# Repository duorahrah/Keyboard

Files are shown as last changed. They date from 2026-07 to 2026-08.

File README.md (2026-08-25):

# Custom 75% Mechanical Keyboard
Designed and built fully custom mechanical keyboard end-to-end, PCB design (KiCad), case design (Onshape) and 3D printing, and firmware (QMK on RP2040).\


## PCB Design



<br/>
-	Designed a RP2040-based custom mechanical keyboard PCB in KiCad with full keyboard matrix and USB-C connectivity
-	Includes full RP2040 support circuitry (crystal, QSPI flash, decoupling, reset and BOOTSEL)
-	Routed and manufactured the PCB

## Case Design

<br/>
-	Modeled custom case in Onshape, accounting for PCB mounting points, USB-C cutout, and switch plate clearance 

## Firmware
-	Developed custom QMK firmware for the keyboard, including multi-layer keymap and matrix/layout configuration to match the custom PCB design

## Challenges
-	USB and RP2040 debugging – I encountered an issue where the keyboard could not be detected by my computer while trying to flash the firmware. I was able to identify the issue as a short between the D+/D- connections through systematic multimeter-based debugging and fix it.
-	3D printer calibration - Case was printed using secondhand ELEGOO Neptune 4 Max, a printer which is known to be finnicky. I did research and looked at experiences from others who had the same printer to learn how to properly calibrate the printer, including replacing the bed springs with silicon spacers, and altering the printer’s configuration file to automatically level the bed and generate a printing mesh. 
-	Obtaining tools and materials – I was unable to gain access to public/free 3D printers over the summer, so I purchased a secondhand printer off Facebook Marketplace. The PCB and parts were ordered from JLCPCB and DigiKey (including $40 for international shipping D:). 

## Results
-	Successfully designed, manufactured, and assembled a working mechanical keyboard for daily use
-	Gained experience across PCB design, mechanical design, manufacturing, firmware development, and hardware debugging

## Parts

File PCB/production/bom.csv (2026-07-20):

Designator | Footprint | Quantity | Value | LCSC Part #
BOOT1, RST1 | SW_SPST_TL3342 | 2 | SW_Push
C1, C10, C2, C3, C6 | 0402 | 5 | 1u
C11, C12 | 0402 | 2 | 22p
C13, C14, C15, C16, C4, C7, C8, C9 | 0402 | 8 | 100n
C5 | 0603 | 1 | 10u
D1, D10, D11, D12, D13, D14, D15, D16, D17, D18, D19, D2, D20, D21, D22, D23, D24, D25, D26, D27, D28, D29, D3, D30, D31, D32, D33, D34, D35, D36, D37, D38, D39, D4, D40, D41, D42, D43, D44, D45, D46, D47, D48, D49, D5, D50, D51, D52, D53, D54, D55, D56, D57, D58, D59, D6, D60, D61, D62, D63, D64, D65, D66, D67, D68, D69, D7, D70, D71, D72, D73, D74, D75, D76, D77, D78, D79, D8, D80, D81, D82, D83, D84, D85, D86, D9 | D_SOD-123 | 86 | D_Small
F1 | 1206 | 1 | Fuse_Small
J1 | JST_SH_SM04B-SRSS-TB_1x04-1MP_P1.00mm_Horizontal | 1 | Conn_01x04
J2 | USB_C_Receptacle_HRO_TYPE-C-31-M-12 | 1 | USB_C_Receptacle_USB2.0_16P
J3 | PinHeader_1x05_P2.54mm_Vertical | 1 | Conn_01x05
MX1, MX10, MX11, MX12, MX13, MX14, MX15, MX16, MX17, MX18, MX19, MX2, MX20, MX21, MX22, MX23, MX24, MX25, MX26, MX27, MX28, MX29, MX3, MX30, MX31, MX33, MX34, MX35, MX36, MX37, MX38, MX39, MX4, MX40, MX41, MX42, MX43, MX44, MX46, MX47, MX49, MX5, MX50, MX51, MX52, MX53, MX54, MX55, MX56, MX57, MX58, MX59, MX6, MX60, MX61, MX62, MX63, MX64, MX65, MX66, MX67, MX68, MX69, MX7, MX70, MX71, MX72, MX73, MX75, MX76, MX8, MX80, MX81, MX82, MX83, MX84, MX85, MX86, MX9 | SW_MX_HS_CPG151101S11_1u | 79 | MX_SW_HS
MX32, MX45 | SW_MX_HS_CPG151101S11_1.5u | 2 | MX_SW_HS
MX48, MX74 | SW_MX_HS_CPG151101S11_1.75u | 2 | MX_SW_HS
MX77, MX78, MX79 | SW_MX_HS_KS-2P02B01-01_1.25u | 3 | MX_SW_HS
R1, R2 | 0402 | 2 | 5.1k
R3, R4, R5 | 0402 | 3 | 5k1
R6, R9 | 0402 | 2 | 1k
R7, R8 | 0402 | 2 | 27
S1 | STAB_MX_P_2u | 1 | MX_stab
S2, S3 | STAB_MX_P_2.25u | 2 | MX_stab
S4 | STAB_MX_P_6.25u | 1 | MX_stab
U1 | SOT-23-3 | 1 | XC6206PxxxMR
U2 | SOT-23-6 | 1 | SRV05-4
U3 | QFN-56-1EP_7x7mm_P0.4mm_EP3.2x3.2mm | 1 | RP2040
U4 | SOIC-8_5.3x5.3mm_P1.27mm | 1 | W25Q128JVS
Y1 | Crystal_SMD_3225-4Pin_3.2x2.5mm | 1 | Crystal_GND24

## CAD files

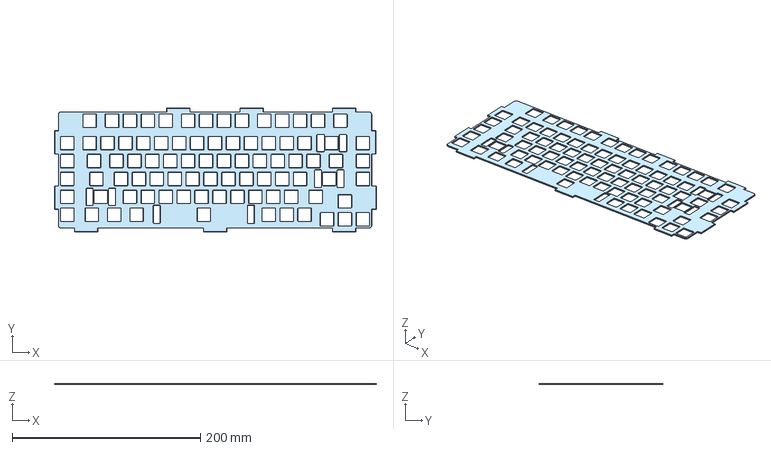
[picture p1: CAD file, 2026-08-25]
Case/plate (3).step
342.4 x 131.8 x 1.50 mm

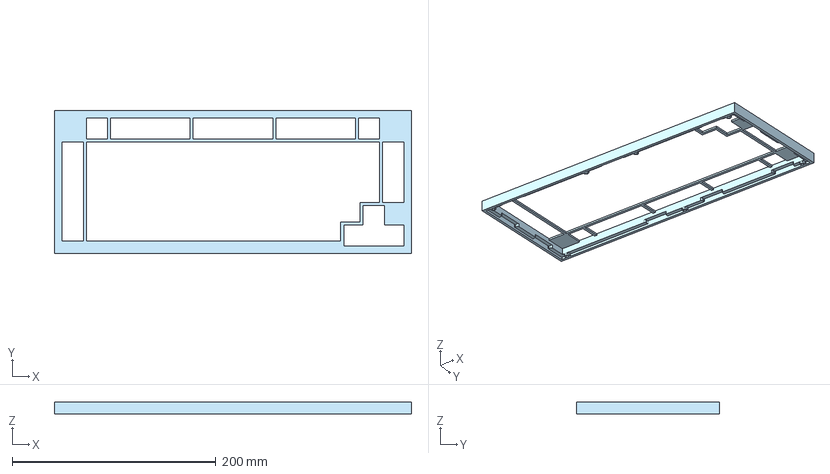
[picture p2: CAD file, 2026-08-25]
Case/Top Case.step
350.2 x 140.6 x 12.0 mm

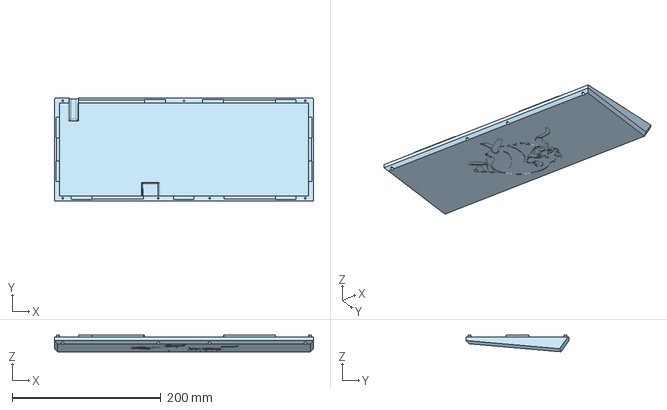
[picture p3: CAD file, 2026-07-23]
Case/Bottom Case.step
348.2 x 138.6 x 22.5 mm

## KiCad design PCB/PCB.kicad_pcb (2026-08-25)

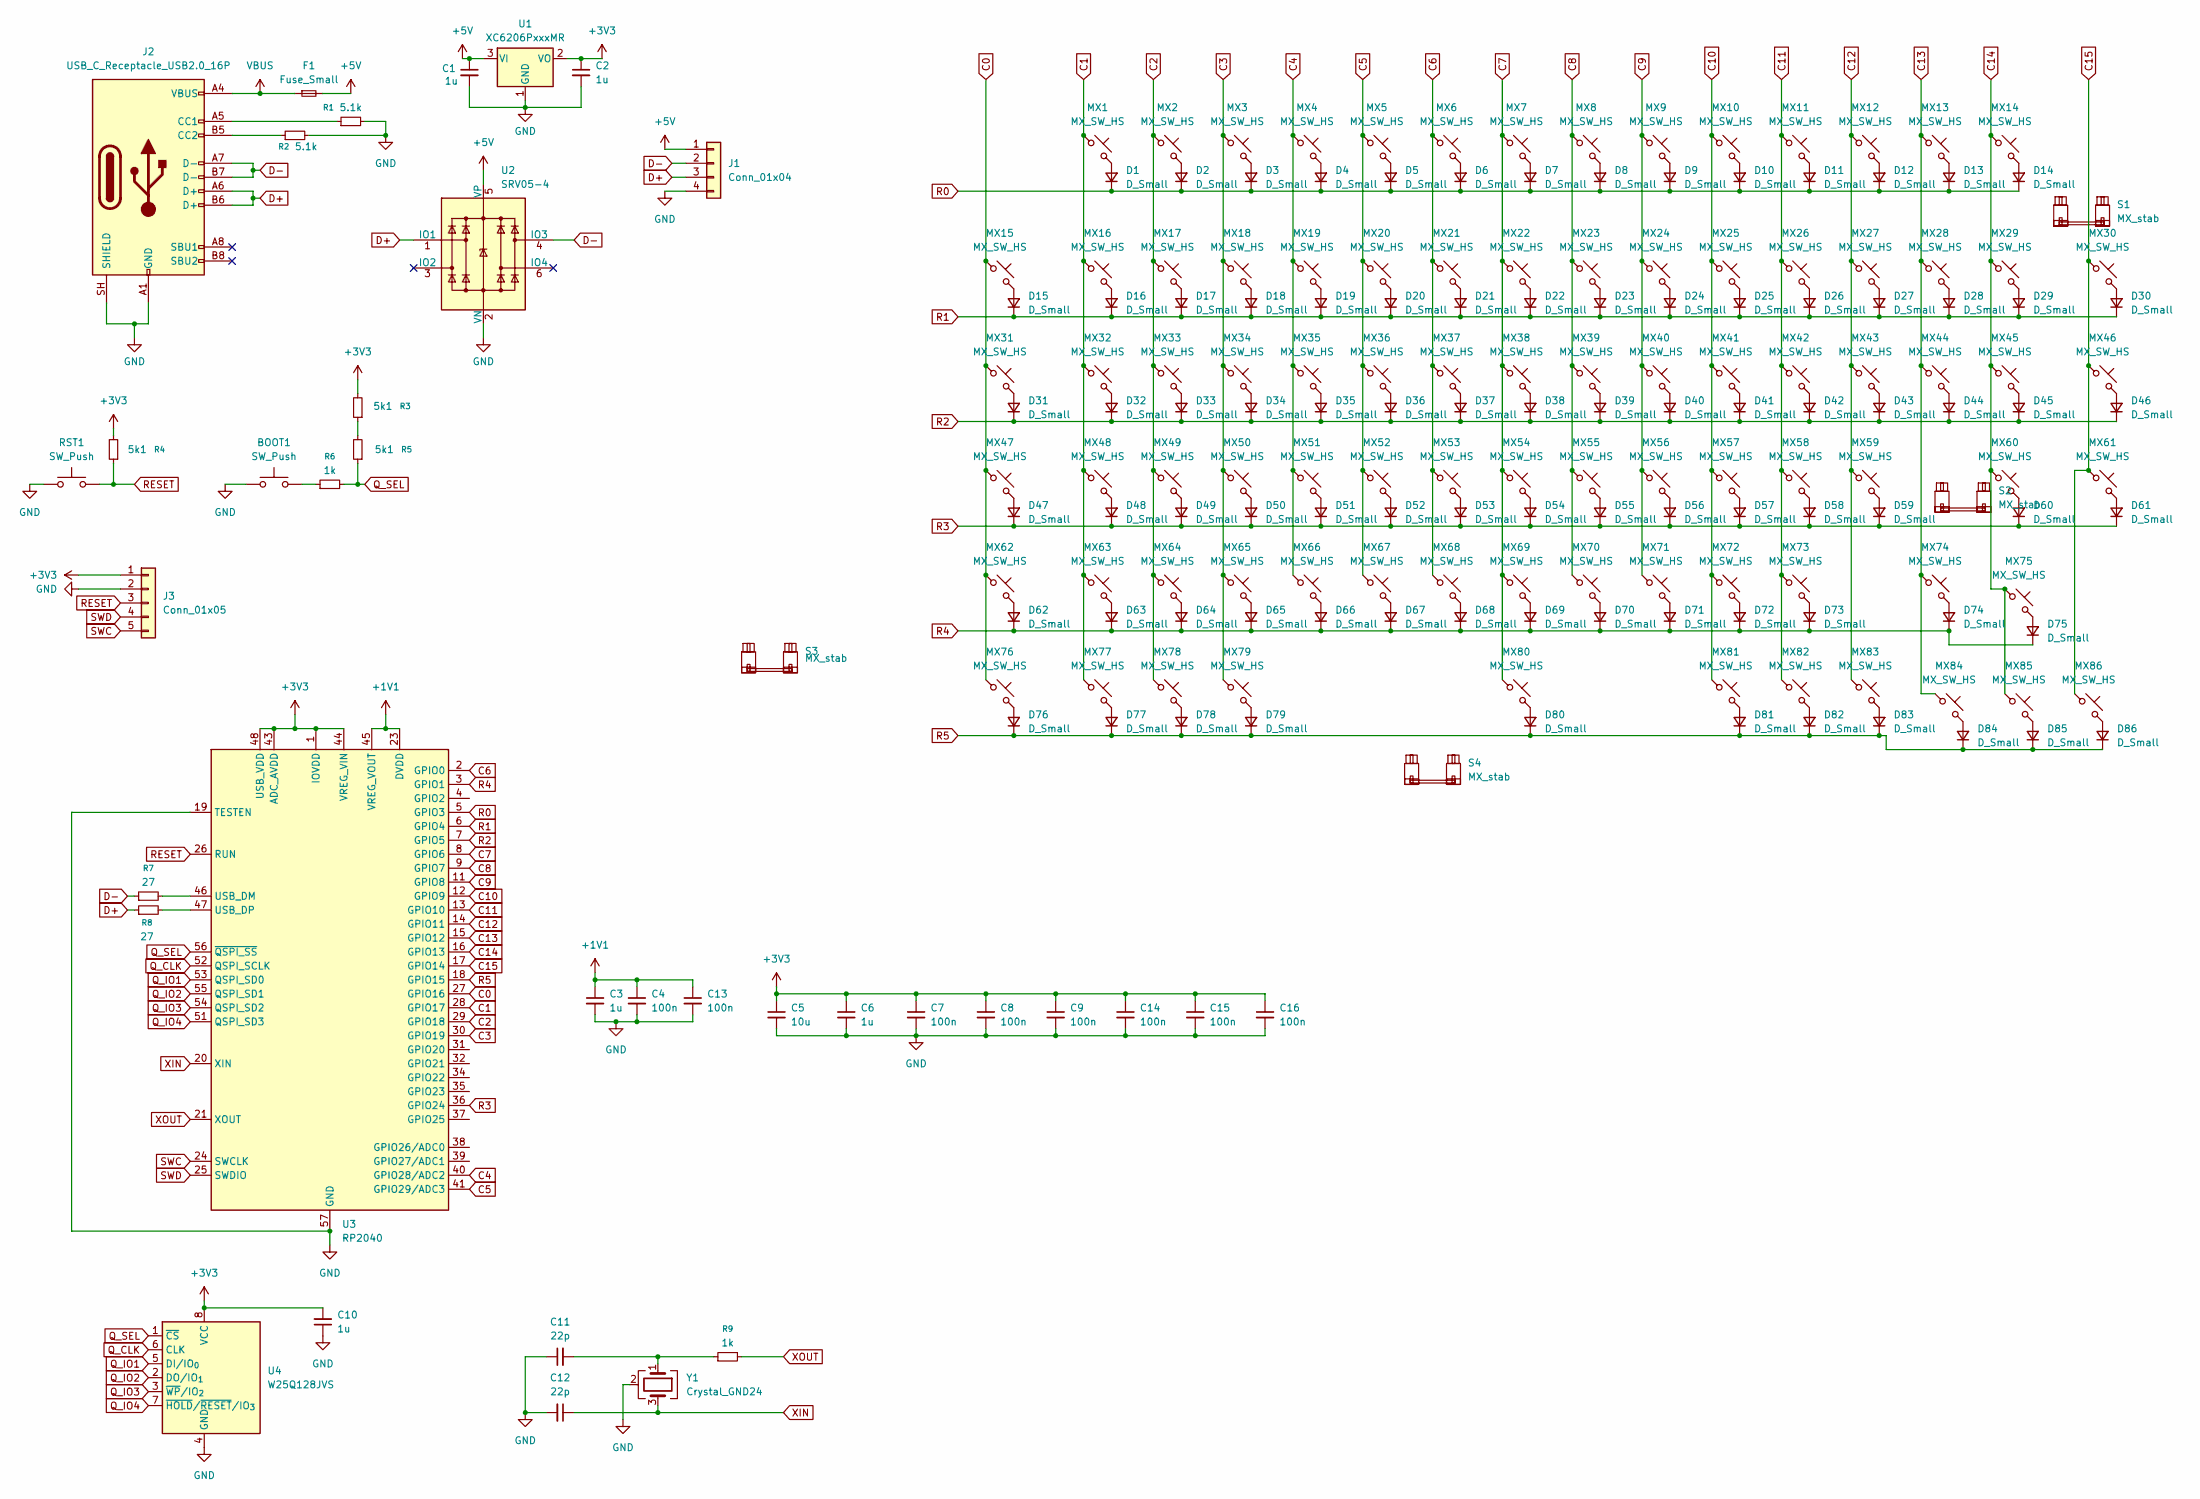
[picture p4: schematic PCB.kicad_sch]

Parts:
BOOT1: SW_Push; SW_SPST_TL3342
C1, C2, C3, C6, C10: 1u; C_0402_1005Metric
C4, C7, C8, C9, C13, C14, C15, C16: 100n; C_0402_1005Metric
C5: 10u; C_0603_1608Metric
C11, C12: 22p; C_0402_1005Metric
D1, D2, D3, D4, D5, D6, D7, D8, D9, D10, D11, D12, D13, D14, D15, D16, D17, D18, D19, D20, D21, D22, D23, D24, D25, D26, D27, D28, D29, D30, D31, D32, D33, D34, D35, D36, D37, D38, D39, D40, D41, D42, D43, D44, D45, D46, D47, D48, D49, D50, D51, D52, D53, D54, D55, D56, D57, D58, D59, D60, D61, D62, D63, D64, D65, D66, D67, D68, D69, D70, D71, D72, D73, D74, D75, D76, D77, D78, D79, D80, D81, D82, D83, D84, D85, D86: D_Small; D_SOD-123
F1: Fuse_Small; Fuse_1206_3216Metric
J1: Conn_01x04; JST_SH_SM04B-SRSS-TB_1x04-1MP_P1.00mm_Horizontal
J2: USB_C_Receptacle_USB2.0_16P; USB_C_Receptacle_HRO_TYPE-C-31-M-12
J3: Conn_01x05; PinHeader_1x05_P2.54mm_Vertical
MX1, MX2, MX3, MX4, MX5, MX6, MX7, MX8, MX9, MX10, MX11, MX12, MX13, MX14, MX15, MX16, MX17, MX18, MX19, MX20, MX21, MX22, MX23, MX24, MX25, MX26, MX27, MX28, MX29, MX30, MX31, MX33, MX34, MX35, MX36, MX37, MX38, MX39, MX40, MX41, MX42, MX43, MX44, MX46, MX47, MX49, MX50, MX51, MX52, MX53, MX54, MX55, MX56, MX57, MX58, MX59, MX60, MX61, MX62, MX63, MX64, MX65, MX66, MX67, MX68, MX69, MX70, MX71, MX72, MX73, MX75, MX76, MX80, MX81, MX82, MX83, MX84, MX85, MX86: MX_SW_HS; SW_MX_HS_CPG151101S11_1u
MX32, MX45: MX_SW_HS; SW_MX_HS_CPG151101S11_1.5u
MX48, MX74: MX_SW_HS; SW_MX_HS_CPG151101S11_1.75u
MX77, MX78, MX79: MX_SW_HS; SW_MX_HS_KS-2P02B01-01_1.25u
R1, R2: 5.1k; R_0402_1005Metric
R3, R4, R5: 5k1; R_0402_1005Metric
R6, R9: 1k; R_0402_1005Metric
R7, R8: 27; R_0402_1005Metric
RST1: SW_Push; SW_SPST_TL3342
S1: MX_stab; STAB_MX_P_2u
S2, S3: MX_stab; STAB_MX_P_2.25u
S4: MX_stab; STAB_MX_P_6.25u
U1: XC6206PxxxMR; SOT-23-3
U2: SRV05-4; SOT-23-6
U3: RP2040; QFN-56-1EP_7x7mm_P0.4mm_EP3.2x3.2mm
U4: W25Q128JVS; SOIC-8_5.3x5.3mm_P1.27mm
Y1: Crystal_GND24; Crystal_SMD_3225-4Pin_3.2x2.5mm

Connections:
+1V1: C3.1, C4.1, C13.1, U3.23 (DVDD), U3.45 (VREG_VOUT), U3.50 (DVDD)
+3V3: C2.1, C5.1, C6.1, C7.1, C8.1, C9.1, C10.2, C14.1, C15.1, C16.1, J3.1, R3.2, R4.2, U1.2 (VO), U3.1 (IOVDD), U3.10 (IOVDD), U3.22 (IOVDD), U3.33 (IOVDD), U3.42 (IOVDD), U3.43 (ADC_AVDD), U3.44 (VREG_VIN), U3.48 (USB_VDD), U3.49 (IOVDD), U4.8 (VCC)
+5V: C1.1, F1.2, J1.1, U1.3 (VI), U2.5 (VP)
C0: MX15.1, MX31.1, MX47.1, MX62.1, MX76.1, U3.27 (GPIO16)
C1: MX1.1, MX16.1, MX32.1, MX48.1, MX63.1, MX77.1, U3.28 (GPIO17)
C2: MX2.1, MX17.1, MX33.1, MX49.1, MX64.1, MX78.1, U3.29 (GPIO18)
C3: MX3.1, MX18.1, MX34.1, MX50.1, MX65.1, MX79.1, U3.30 (GPIO19)
C4: MX4.1, MX19.1, MX35.1, MX51.1, MX66.1, U3.40 (GPIO28/ADC2)
C5: MX5.1, MX20.1, MX36.1, MX52.1, MX67.1, U3.41 (GPIO29/ADC3)
C6: MX6.1, MX21.1, MX37.1, MX53.1, MX68.1, U3.2 (GPIO0)
C7: MX7.1, MX22.1, MX38.1, MX54.1, MX69.1, MX80.1, U3.8 (GPIO6)
C8: MX8.1, MX23.1, MX39.1, MX55.1, MX70.1, U3.9 (GPIO7)
C9: MX9.1, MX24.1, MX40.1, MX56.1, MX71.1, U3.11 (GPIO8)
C10: MX10.1, MX25.1, MX41.1, MX57.1, MX72.1, MX81.1, U3.12 (GPIO9)
C11: MX11.1, MX26.1, MX42.1, MX58.1, MX73.1, MX82.1, U3.13 (GPIO10)
C12: MX12.1, MX27.1, MX43.1, MX59.1, MX83.1, U3.14 (GPIO11)
C13: MX13.1, MX28.1, MX44.1, MX74.1, MX84.1, U3.15 (GPIO12)
C14: MX14.1, MX29.1, MX45.1, MX60.1, MX75.1, MX85.1, U3.16 (GPIO13)
C15: MX30.1, MX46.1, MX61.1, MX86.1, U3.17 (GPIO14)
D+: J1.3, J2.A6 (D+), J2.B6 (D+), R8.1, U2.1 (IO1)
D-: J1.2, J2.A7 (D-), J2.B7 (D-), R7.1, U2.4 (IO3)
GND: BOOT1.1, C1.2, C2.2, C3.2, C4.2, C5.2, C6.2, C7.2, C8.2, C9.2, C10.1, C11.1, C12.2, C13.2, C14.2, C15.2, C16.2, J1.4, J2.A1 (GND), J2.A12 (GND), J2.B1 (GND), J2.B12 (GND), J2.SH (SHIELD), J3.2, R1.2, R2.2, RST1.1, U1.1 (GND), U2.2 (VN), U3.19 (TESTEN), U3.57 (GND), U4.4 (GND), Y1.2 (G), Y1.4 (G)
unnamed: BOOT1.2, R6.1
unnamed: C11.2, R9.1, Y1.1
unnamed: D1.2 (A), MX1.2
unnamed: D2.2 (A), MX2.2
unnamed: D3.2 (A), MX3.2
unnamed: D4.2 (A), MX4.2
unnamed: D5.2 (A), MX5.2
unnamed: D6.2 (A), MX6.2
unnamed: D7.2 (A), MX7.2
unnamed: D8.2 (A), MX8.2
unnamed: D9.2 (A), MX9.2
unnamed: D10.2 (A), MX10.2
unnamed: D11.2 (A), MX11.2
unnamed: D12.2 (A), MX12.2
unnamed: D13.2 (A), MX13.2
unnamed: D14.2 (A), MX14.2
unnamed: D15.2 (A), MX15.2
unnamed: D16.2 (A), MX16.2
unnamed: D17.2 (A), MX17.2
unnamed: D18.2 (A), MX18.2
unnamed: D19.2 (A), MX19.2
unnamed: D20.2 (A), MX20.2
unnamed: D21.2 (A), MX21.2
unnamed: D22.2 (A), MX22.2
unnamed: D23.2 (A), MX23.2
unnamed: D24.2 (A), MX24.2
unnamed: D25.2 (A), MX25.2
unnamed: D26.2 (A), MX26.2
unnamed: D27.2 (A), MX27.2
unnamed: D28.2 (A), MX28.2
unnamed: D29.2 (A), MX29.2
unnamed: D30.2 (A), MX30.2
unnamed: D31.2 (A), MX31.2
unnamed: D32.2 (A), MX32.2
unnamed: D33.2 (A), MX33.2
unnamed: D34.2 (A), MX34.2
unnamed: D35.2 (A), MX35.2
unnamed: D36.2 (A), MX36.2
unnamed: D37.2 (A), MX37.2
unnamed: D38.2 (A), MX38.2
unnamed: D39.2 (A), MX39.2
unnamed: D40.2 (A), MX40.2
unnamed: D41.2 (A), MX41.2
unnamed: D42.2 (A), MX42.2
unnamed: D43.2 (A), MX43.2
unnamed: D44.2 (A), MX44.2
unnamed: D45.2 (A), MX45.2
unnamed: D46.2 (A), MX46.2
unnamed: D47.2 (A), MX47.2
unnamed: D48.2 (A), MX48.2
unnamed: D49.2 (A), MX49.2
unnamed: D50.2 (A), MX50.2
unnamed: D51.2 (A), MX51.2
unnamed: D52.2 (A), MX52.2
unnamed: D53.2 (A), MX53.2
unnamed: D54.2 (A), MX54.2
unnamed: D55.2 (A), MX55.2
unnamed: D56.2 (A), MX56.2
unnamed: D57.2 (A), MX57.2
unnamed: D58.2 (A), MX58.2
unnamed: D59.2 (A), MX59.2
unnamed: D60.2 (A), MX60.2
unnamed: D61.2 (A), MX61.2
unnamed: D62.2 (A), MX62.2
unnamed: D63.2 (A), MX63.2
unnamed: D64.2 (A), MX64.2
unnamed: D65.2 (A), MX65.2
unnamed: D66.2 (A), MX66.2
unnamed: D67.2 (A), MX67.2
unnamed: D68.2 (A), MX68.2
unnamed: D69.2 (A), MX69.2
unnamed: D70.2 (A), MX70.2
unnamed: D71.2 (A), MX71.2
unnamed: D72.2 (A), MX72.2
unnamed: D73.2 (A), MX73.2
unnamed: D74.2 (A), MX74.2
unnamed: D75.2 (A), MX75.2
unnamed: D76.2 (A), MX76.2
unnamed: D77.2 (A), MX77.2
unnamed: D78.2 (A), MX78.2
unnamed: D79.2 (A), MX79.2
unnamed: D80.2 (A), MX80.2
unnamed: D81.2 (A), MX81.2
unnamed: D82.2 (A), MX82.2
unnamed: D83.2 (A), MX83.2
unnamed: D84.2 (A), MX84.2
unnamed: D85.2 (A), MX85.2
unnamed: D86.2 (A), MX86.2
unnamed: J2.A5 (CC1), R1.1
unnamed: J2.B5 (CC2), R2.1
unnamed: R3.1, R5.2
unnamed: R7.2, U3.46 (USB_DM)
unnamed: R8.2, U3.47 (USB_DP)
Q_CLK: U3.52 (QSPI_SCLK), U4.6 (CLK)
Q_IO1: U3.53 (QSPI_SD0), U4.5 (DI/IO_{0})
Q_IO2: U3.55 (QSPI_SD1), U4.2 (DO/IO_{1})
Q_IO3: U3.54 (QSPI_SD2), U4.3 (~WP/IO_{2})
Q_IO4: U3.51 (QSPI_SD3), U4.7 (~HOLD/~RESET/IO_{3})
Q_SEL: R5.1, R6.2, U3.56 (~QSPI_SS), U4.1 (~CS)
R0: D1.1 (K), D2.1 (K), D3.1 (K), D4.1 (K), D5.1 (K), D6.1 (K), D7.1 (K), D8.1 (K), D9.1 (K), D10.1 (K), D11.1 (K), D12.1 (K), D13.1 (K), D14.1 (K), U3.5 (GPIO3)
R1: D15.1 (K), D16.1 (K), D17.1 (K), D18.1 (K), D19.1 (K), D20.1 (K), D21.1 (K), D22.1 (K), D23.1 (K), D24.1 (K), D25.1 (K), D26.1 (K), D27.1 (K), D28.1 (K), D29.1 (K), D30.1 (K), U3.6 (GPIO4)
R2: D31.1 (K), D32.1 (K), D33.1 (K), D34.1 (K), D35.1 (K), D36.1 (K), D37.1 (K), D38.1 (K), D39.1 (K), D40.1 (K), D41.1 (K), D42.1 (K), D43.1 (K), D44.1 (K), D45.1 (K), D46.1 (K), U3.7 (GPIO5)
R3: D47.1 (K), D48.1 (K), D49.1 (K), D50.1 (K), D51.1 (K), D52.1 (K), D53.1 (K), D54.1 (K), D55.1 (K), D56.1 (K), D57.1 (K), D58.1 (K), D59.1 (K), D60.1 (K), D61.1 (K), U3.36 (GPIO24)
R4: D62.1 (K), D63.1 (K), D64.1 (K), D65.1 (K), D66.1 (K), D67.1 (K), D68.1 (K), D69.1 (K), D70.1 (K), D71.1 (K), D72.1 (K), D73.1 (K), D74.1 (K), D75.1 (K), U3.3 (GPIO1)
R5: D76.1 (K), D77.1 (K), D78.1 (K), D79.1 (K), D80.1 (K), D81.1 (K), D82.1 (K), D83.1 (K), D84.1 (K), D85.1 (K), D86.1 (K), U3.18 (GPIO15)
RESET: J3.3, R4.1, RST1.2, U3.26 (RUN)
SWC: J3.5, U3.24 (SWCLK)
SWD: J3.4, U3.25 (SWDIO)
VBUS: F1.1, J2.A4 (VBUS), J2.A9 (VBUS), J2.B4 (VBUS), J2.B9 (VBUS)
XIN: C12.1, U3.20 (XIN), Y1.3
XOUT: R9.2, U3.21 (XOUT)

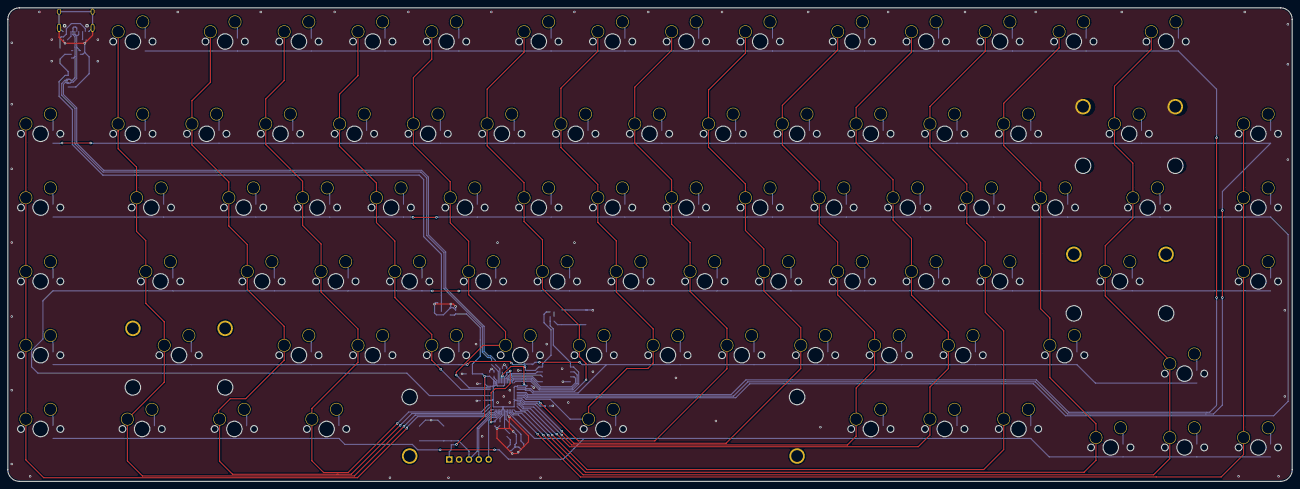
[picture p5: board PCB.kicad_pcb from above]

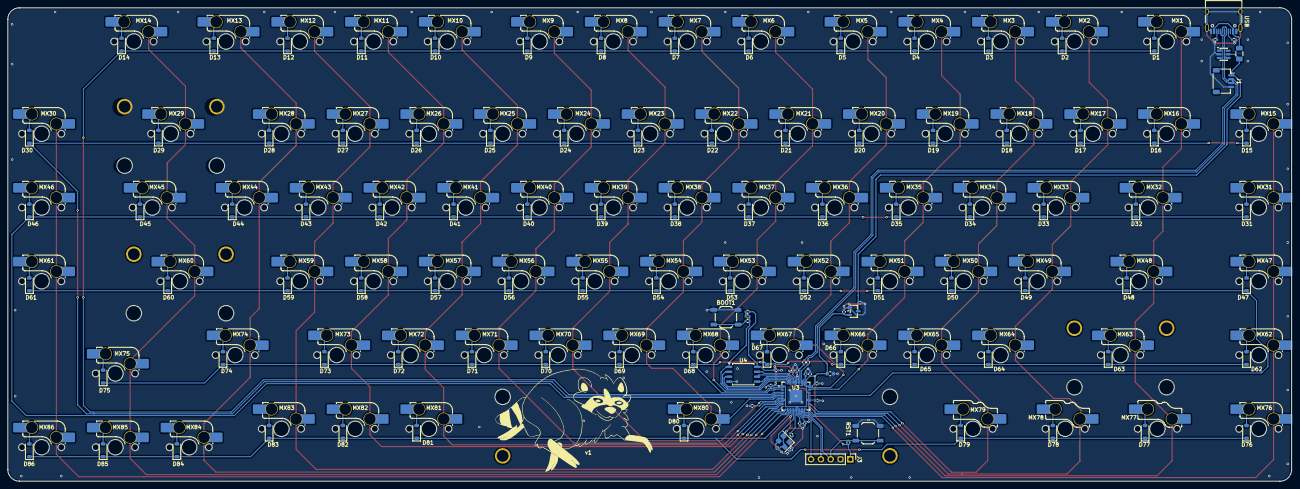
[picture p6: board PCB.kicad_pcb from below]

Board: 2 copper layers, 331.5 x 122.2 mm, 212 parts (209 on the bottom side), 133 nets.

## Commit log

2026-07-18 Initial commit 2
    [PCB.kicad_pcb, PCB.kicad_sch]
2026-07-18 keyboard matrix done
    [PCB.kicad_pcb, PCB.kicad_sch]
2026-07-19 fixing footprints
    [PCB.kicad_pcb]
2026-07-20 gerbers + bom + position files
    [PCB-B_Cu.gbr, PCB-B_Mask.gbr, PCB-B_Silkscreen.gbr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]
2026-07-23 kb case
    [Bottom Case.step, Top Case.step, plate (3).step]
2026-08-25 updated cad files
    [Top Case.step, plate (3).step]
